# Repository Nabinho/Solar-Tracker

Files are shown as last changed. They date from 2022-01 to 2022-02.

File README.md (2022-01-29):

# Solar-Tracker
Solar Tracker project with Arduino platform.

Project based on [RoboCore's Solar Panel](https://www.robocore.net/fonte/painel-solar-2w) with TEMT600 ambient light sensors. Controlled by Teensy 3.2, Pololu A-Star Micro and Open Log Module. HMI made with LCD 16x2 with I2C interface and M5Stack CardKB.

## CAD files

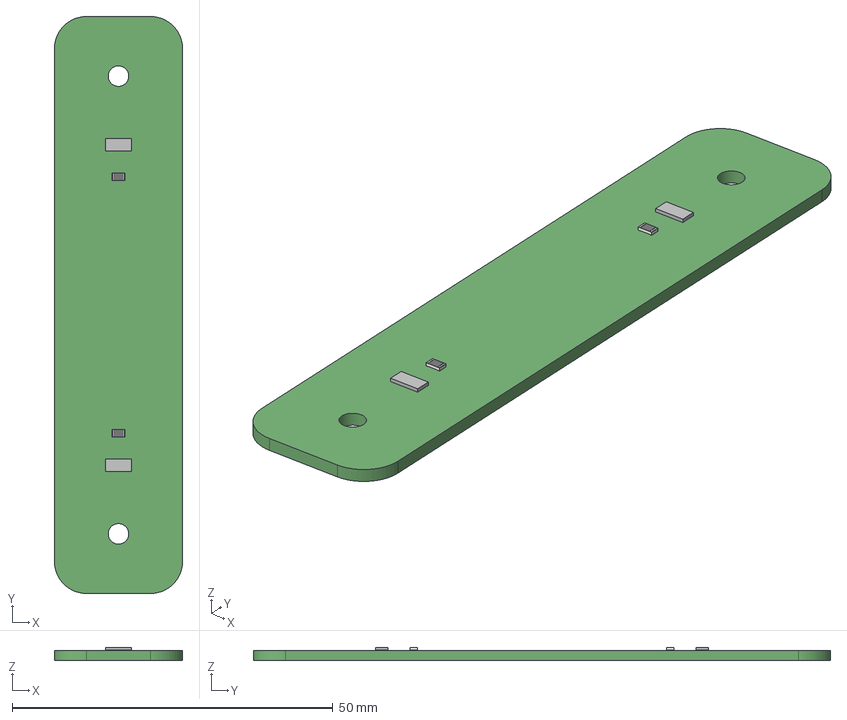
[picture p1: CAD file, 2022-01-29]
SolarTracker_Project/Electronic/TEMT6000_SolarPanel_Sensor/TEMT6000_SolarPanel_Sensor.step
20.0 x 90.0 x 2.10 mm

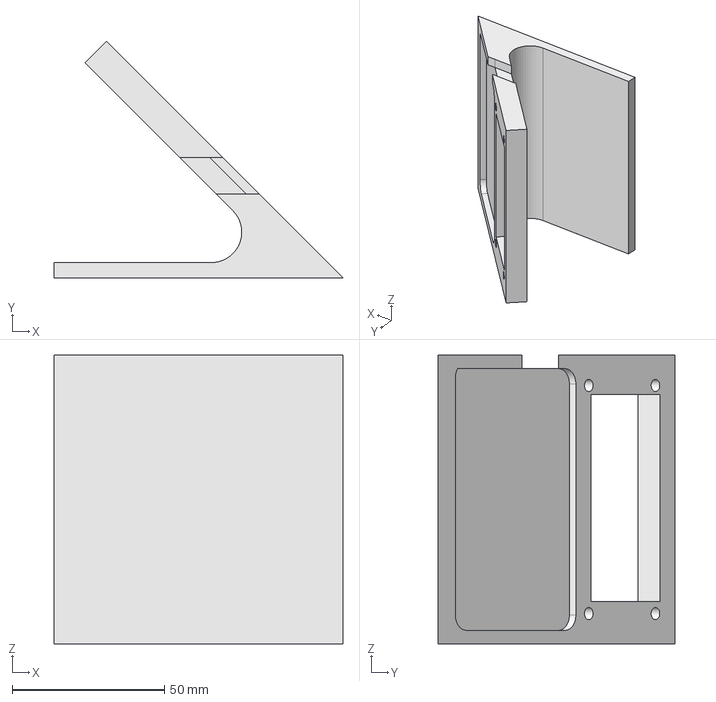
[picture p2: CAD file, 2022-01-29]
SolarTracker_Project/Mecanic/IHM_support.FCStd
95.0 x 77.8 x 95.0 mm

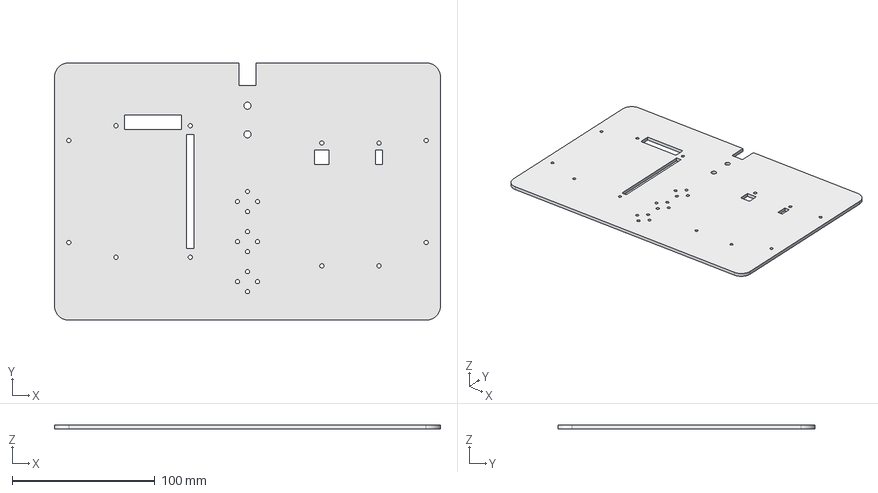
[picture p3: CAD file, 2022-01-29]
SolarTracker_Project/Mecanic/Solar_Panel_Support.FCStd
270.0 x 180.0 x 3.00 mm

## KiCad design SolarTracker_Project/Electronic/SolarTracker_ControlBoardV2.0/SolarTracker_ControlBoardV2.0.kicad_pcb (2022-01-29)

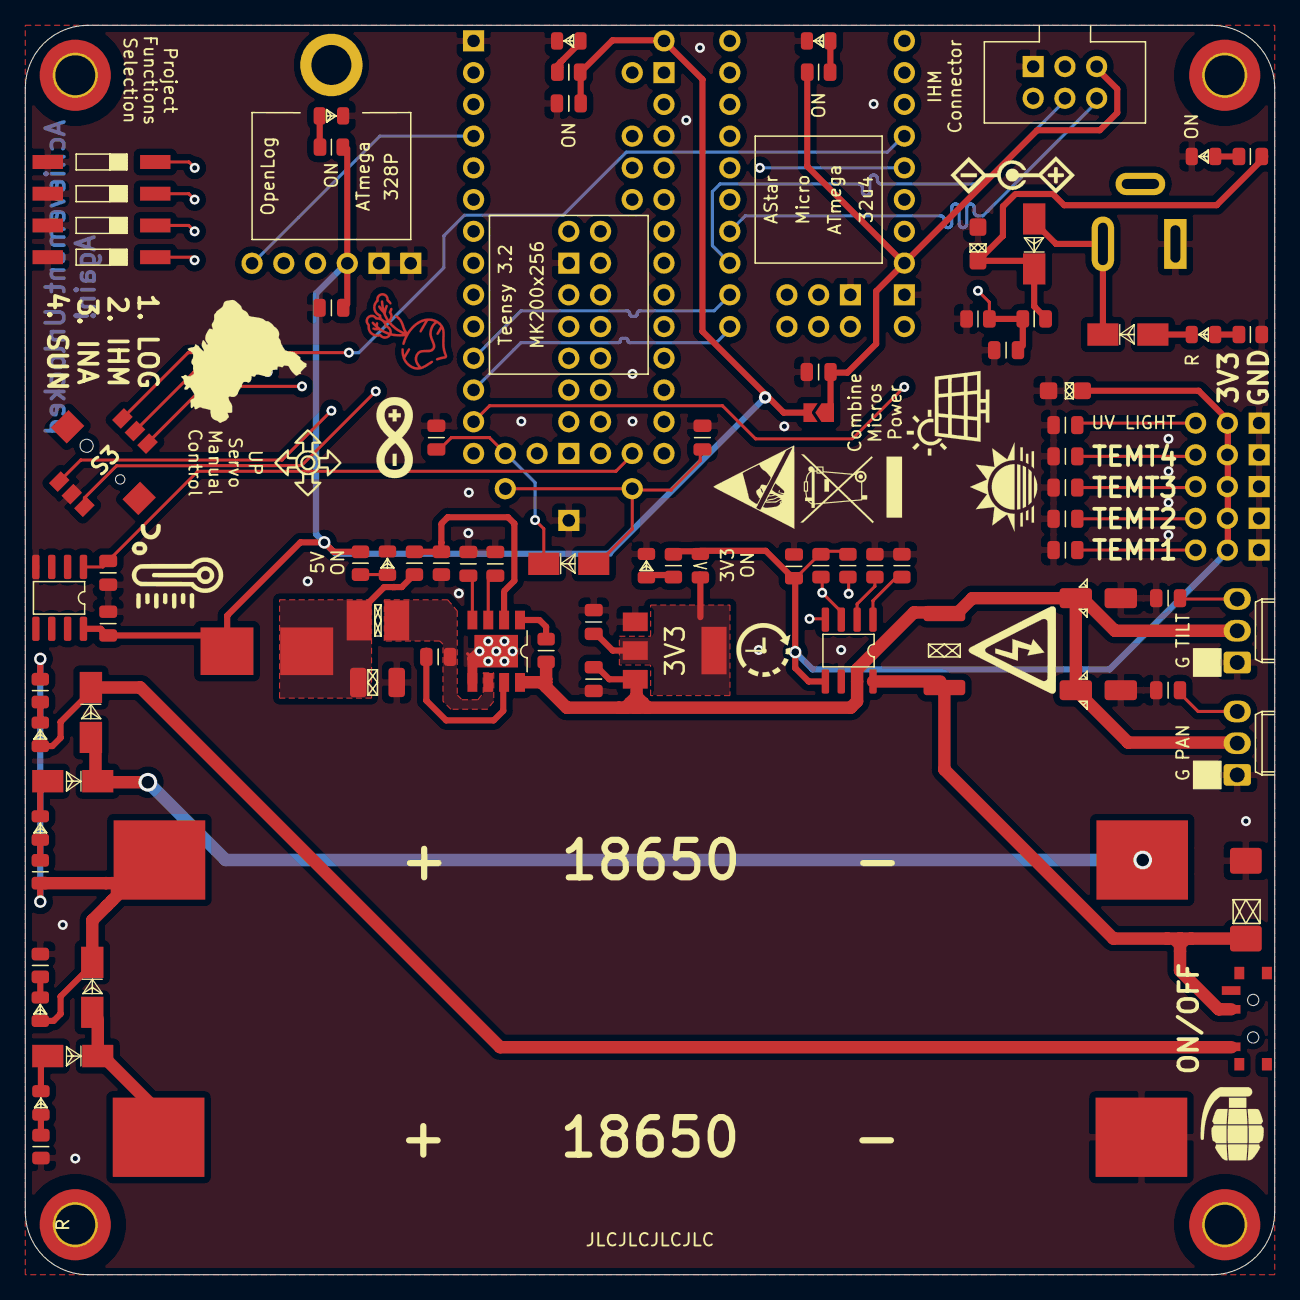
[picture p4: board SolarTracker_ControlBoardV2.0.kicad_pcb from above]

Board: 4 copper layers, 100.0 x 100.0 mm, 88 parts (0 on the bottom side), 66 nets.

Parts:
BT1, BT2: 18650; BatteryHolder_Keystone_1042_1x18650
BT3: CR2032; CR2032_BatteryHolder_Vertical
C1: 22uF; CP_EIA-7343-31_Kemet-D
C2, C5, C11, C12, C18, C20, C22, C23, C24, C25, C26, C27: 1uF; C_0805_2012Metric
C3, C4: 10uF; CP_Elec_4x5.3
C6, C7, C10, C13, C14, C15, C16, C17, C19: 100nF; C_0805_2012Metric
C8: 47uF; CP_EIA-3528-21_Kemet-B
C9, C21: 10uF; CP_EIA-3216-18_Kemet-A
D1, D4: RED; LED_0805_2012Metric
D2, D5, D12, D18: M7; D_SMA
D3, D6, D13: SS34; D_SMA
D7, D8, D9, D10, D14: B; LED_0805_2012Metric
D11: R; LED_0805_2012Metric
D15, D16, D17: G; LED_0805_2012Metric
F1: Fuse; FUSE_0154004.DR
F2: Fuse; Fuse_0805_2012Metric
J1: Servo_Pan; Molex_KK-254_AE-6410-03A_1x03_P2.54mm_Vertical
J2: Servo_Tilt; Molex_KK-254_AE-6410-03A_1x03_P2.54mm_Vertical
J3: Barrel_Jack_Switch; BarrelJack_Wuerth_6941xx301002
J4: Conn_03x05_Male; PinHeader_3x05_P2.54mm_Vertical
J5: Conn_02x03_Odd_Even; IDC-Header_2x03_P2.54mm_Vertical
JP1: SolderJumper_2_Open; SolderJumper-2_P1.3mm_Open_TrianglePad1.0x1.5mm
L1: 3,3uH; CD32
R1, R2, R3, R4, R10, R14, R15, R25, R26, R27: 1k; R_0805_2012Metric
R5: 100; R_2512_6332Metric
R6, R7, R16: 10k; R_0805_2012Metric
R8, R9: 4k7; R_0805_2012Metric
R11: 100k; R_0805_2012Metric
R12: 124k; R_0805_2012Metric
R13: 22k1; R_0805_2012Metric
R17: 15k; R_0805_2012Metric
R18: 12k; R_0805_2012Metric
S3: SKRHABE010
SW1: SW_SPDT; SW_SPDT_PCM12
SW2: SW_DIP_x04; SW_DIP_SPSTx04_Slide_9.78x12.34mm_W8.61mm_P2.54mm
U1: INA219AxD; SOIC-8_3.9x4.9mm_P1.27mm
U2: AP65552SP-13; Diodes-AP65552SP-13-06_2015-0-0
U3: Teensy3.2; Teensy_3.2
U4: LM35-D; SOIC-8_3.9x4.9mm_P1.27mm
U5: OpenLog
U6: AStar_Micro
U7: AMS1117-3.3; SOT-223-3_TabPin2

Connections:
5V: C22.1, J5.1, JP1.1, R25.1, U6.13
+3V3: C2.1, C21.1, F2.1, J4.1, R8.1, R9.1, R10.2, U1.5
+5V: C12.1, C18.1, C20.2, F1.1, JP1.2, R14.2, R26.1, R27.1, U3.33, U4.8, U5.4
A0: R7.1, U1.2
A1: R6.1, U1.1
AStar_SCL: J5.2, U6.7
AStar_SDA: J5.4, U6.8
A_SolarPanel: C10.1, R17.2, R18.1, U3.28
BS: C7.1, U2.7
BT_A: S3.1, U6.19
BT_B: S3.4, U6.18
BT_C: S3.3, U6.17
BT_D: S3.6, U6.16
BT_M: S3.2, U6.20
DIP1: SW2.1, U3.8
DIP2: SW2.2, U3.7
DIP3: SW2.3, U3.6
DIP4: SW2.4, U3.5
FB: R12.2, R13.1, U2.2
GND: BT1.2, BT3.2, C1.2, C2.2, C3.2, C4.2, C5.2, C6.2, C8.2, C9.2, C10.2, C11.2, C12.2, C13.2, C14.2, C15.2, C16.2, C17.2, C18.2, C19.2, C20.1, C21.2, C22.2, C23.2, C24.2, C25.1, C26.2, C27.2, D9.1, D10.1, D14.1, D15.1, D16.1, D17.1, J1.1, J2.1, J3.2, J4.7, J5.5, R1.2, R3.2, R6.2, R7.2, R13.2, R15.2, R18.2, S3.5, SW2.5, SW2.6, SW2.7, SW2.8, U1.6, U2.5, U2.9, U3.1, U3.17, U3.53, U4.4, U5.5, U5.6, U6.12, U6.21, U7.1
LM35: C19.1, U3.19, U4.1
unnamed: BT1.1, D2.1, D3.2
unnamed: BT2.1, D5.1, D6.2
unnamed: BT3.1, C11.1, D18.2
unnamed: C5.1, U2.3
unnamed: C6.1, U2.4
unnamed: C8.1, F1.2, L1.2, R12.1
unnamed: C24.1, F2.2, U7.2
unnamed: D1.1, D2.2
unnamed: D1.2, R1.1
unnamed: D4.1, D5.2
unnamed: D4.2, R2.1
unnamed: D7.1, R4.1
unnamed: D8.1, R3.1
unnamed: D9.2, R10.1
unnamed: D10.2, R14.1
unnamed: D11.1, D12.2
unnamed: D11.2, R15.1
unnamed: D12.1, D13.2, J3.1
unnamed: D14.2, R16.1
unnamed: D15.2, R25.2
unnamed: D16.2, R26.2
unnamed: D17.2, R27.2
unnamed: R11.2, U2.1
SW: C7.2, L1.1, U2.6
Servo_Pan: C26.1, J1.3, U6.6
Servo_Tilt: C25.2, J2.3, U6.5
TEMT1: C13.1, J4.2, U3.21
TEMT2: C14.1, J4.3, U3.22
TEMT3: C15.1, J4.4, U3.23
TEMT4: C16.1, J4.5, U3.24
Teensy_RX1: U3.2, U5.3
Teensy_RX2: U3.11, U6.9
Teensy_Reset1: U3.4, U5.1
Teensy_Reset2: U3.13, U6.15
Teensy_SCL: R9.2, U1.4, U3.26
Teensy_SDA: R8.2, U1.3, U3.25
Teensy_TX1: U3.3, U5.2
Teensy_TX2: U3.12, U6.10
UV: C17.1, J4.6, U3.27
VBAT1: BT2.2, D3.1, D8.2, R2.2, R4.2
VBAT2: D6.1, D7.2, SW1.1
VBUS: C3.1, C4.1, C23.1, J1.2, J2.2, R5.2, R11.1, U1.7, U2.8, U7.3
VDD: C1.1, R5.1, SW1.2, U1.8
VPP: C9.1, D13.1, R16.2, R17.1
VS: C27.1, D18.1, U3.15

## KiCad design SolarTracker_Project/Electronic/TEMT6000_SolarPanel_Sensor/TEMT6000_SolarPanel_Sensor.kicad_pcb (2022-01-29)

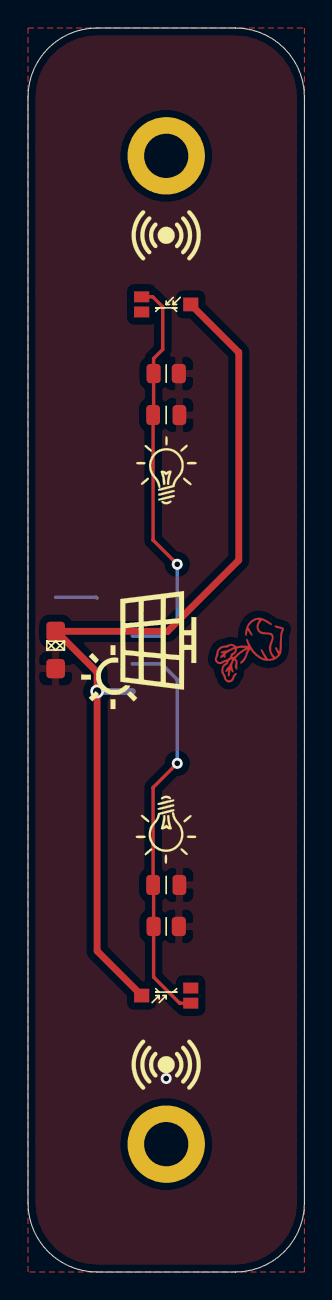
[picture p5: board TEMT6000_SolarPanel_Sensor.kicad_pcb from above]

Board: 2 copper layers, 20.0 x 90.0 mm, 8 parts (1 on the bottom side), 4 nets.

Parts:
C1: 1uF; CP_EIA-3216-18_Kemet-A
C2, C3: 100nF; C_0805_2012Metric
J1: Conn_01x04; JST_PH_S4B-PH-SM4-TB_1x04-1MP_P2.00mm_Horizontal
Q1, Q2: TEMT6000X01; Vishay_Semiconductors-TEMT6000X01-Manufacturer_Recommended
R1, R2: 10k; R_0805_2012Metric

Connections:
+3V3: C1.1, J1.1, Q1.3, Q2.3
GND: C1.2, C2.2, C3.2, J1.4, R1.2, R2.2
Signal1: C2.1, J1.2, Q1.1, R1.1
Signal2: C3.1, J1.3, Q2.1, R2.1

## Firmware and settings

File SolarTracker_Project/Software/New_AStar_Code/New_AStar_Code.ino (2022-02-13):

/*******************************************************************************
  Solar Tracker Project Slave Code
  (v1.5 - 12/02/2022)

  Created by: @Nabinho
  CardKB IHM Reference - https://docs.m5stack.com/#/en/unit/cardkb

  This program is free software: you can redistribute it and/or modify
  it under the terms of the GNU Lesser General Public License as published by
  the Free Software Foundation, either version 3 of the License, or
  (at your option) any later version (<https://www.gnu.org/licenses/>).
*******************************************************************************/

//------------------------------------------------------------------------------
//Code Setup

// Board Selection Verification
#if !defined(ARDUINO_AVR_A_STAR_32U4) // Pololu A Star Micro
#error Use this code with Pololu AStar Micro
#endif

// DEBUG Definition
// Comment for cancel serial monitor DEBUG
#define DEBUG

//Libraries
#include <LiquidCrystal_I2C.h>
#include <Servo.h>
#include <Arduino.h>
#include <EEPROM.h>

//IHM Communication Variables
//LCD variables
#define LCD_ADDR 0x3F
#define N_COLUMNS 16
#define N_ROWS 2
LiquidCrystal_I2C lcd(LCD_ADDR, N_COLUMNS, N_ROWS);
//Keyboard variables
// Keyboard variables
#define CARDKB_ADDR 0x5F
char leitura;
String letter;
String message;
String leituraHEX;
int index;
bool log_read = false;

//Times Variables
unsigned long time_before = 0;
const int SECOND = 2000;

//Servos Objects
Servo servo_pan;
Servo servo_tilt;

//Servo Control Variables
int memory_pan = 0;
int memory_tilt = 1;
int pos_pan;
int pos_tilt;

//Pan servo variables
const int pin_pan = 4;
const int pan_max = 180;
const int pan_min = 0;

//Tilt servo variables
const int pin_tilt = 5;
const int tilt_max = 180;
const int tilt_min = 90;

//Joystick middle button variables
const int pin_middle = 7;
int readingM;
int buttonMState;
int lastButtonMState = HIGH;
unsigned long lastMDebounceTime = 0;
const int MdebounceDelay = 500;
bool manual_control = false;

//Joystick left-right variables
const int pin_left = A0;
const int pin_right = 8;
int readingL;
int readingR;
int buttonLState;
int buttonRState;
int lastButtonLState = HIGH;
int lastButtonRState = HIGH;
unsigned long lastLRDebounceTime = 0;
const int LRdebounceDelay = 100;

//Joystick up-down variables
const int pin_up = 6;
const int pin_down = 9;
int readingU;
int readingD;
int buttonUState;
int buttonDState;
int lastButtonUState = HIGH;
int lastButtonDState = HIGH;
unsigned long lastUDDebounceTime = 0;
const int UDdebounceDelay = 100;

//------------------------------ IHM Handler -----------------------------------
void IHM_control() {

  if (!manual_control) {
    Wire.requestFrom(CARDKB_ADDR, 1);
    while (Wire.available()) {
      leitura = Wire.read();
      if (leitura != 0) {
        leituraHEX = String(leitura, HEX);
#ifdef DEBUG
        Serial.print("CardKB Reading = ");
        Serial.println(leitura);
        Serial.print("CardKB Reading in HEX = ");
        Serial.println(leituraHEX);
#endif
        if (leituraHEX == "8") {
          index = message.length();
          message.remove(index - 1);
          index = message.length();
          lcd.clear();
          lcd.print("Message:  " + message);
#ifdef DEBUG
          Serial.println("Backspace pressed");
          Serial.print("Message - ");
          Serial.println(message);
#endif
        } else if (leituraHEX == "ff8b") {
          message = "";
#ifdef DEBUG
          Serial.println("Delete pressed");
          Serial.print("message erased.");
          Serial.println(message);
#endif
        } else if (leituraHEX == "d" || leituraHEX == "a3") {
#ifdef DEBUG
          Serial.println("Enter pressed - Sending message and waiting return...");
#endif
          log_read = true;
          digitalWrite(LED_BUILTIN, HIGH);
        } else if (leituraHEX == "1b" || leituraHEX == "ff80") {
#ifdef DEBUG
          Serial.println("Esc pressed - leaving message request mode...");
#endif
          digitalWrite(LED_BUILTIN, LOW);
          Serial1.print("IHMREADOFF");
          lcd.clear();
          log_read = false;
          message = "";
        } else if (index > 6) {
#ifdef DEBUG
          Serial.print("Message too long - ignoring last character pressed - ");
          Serial.println(message);
#endif
          message.remove(index - 1);
          lcd.clear();
          lcd.print("Message:  " + message);
          lcd.setCursor(0, 1);
          lcd.print("Message too long");
        } else{
          letter = String(leitura);
          message += letter;
          index = message.length();
          lcd.clear();
          lcd.print("Message:  " + message);
#ifdef DEBUG
          Serial.print("Message - ");
          Serial.println(message);
#endif
        }
      }
    }
  }
  
}

//----------------------------- Servo Handler ----------------------------------
void servo_control(){

  //Reads button states
  readingM = digitalRead(pin_middle);

  //Debounces time update
  if (readingM != lastButtonMState){
    // reset the debouncing timer
    lastMDebounceTime = millis();
  }

  //Debounce verification
  if ((millis() - lastMDebounceTime) > MdebounceDelay){
    if (readingM != buttonMState){
      buttonMState = readingM;
      if (buttonMState == LOW){
        //Inverts manual control funtion state
        manual_control = !manual_control;
        if (manual_control){
          //Attaches Servos
#ifdef DEBUG
          Serial.println("ENTERING MANUAL MODE");
#endif
          lcd.clear();
          lcd.print(" ENTERED SERVOS ");
          lcd.setCursor(0, 1);
          lcd.print(" MANUAL CONTROL ");
        }
        else{
          //Detaches Servos
#ifdef DEBUG
          Serial.println("EXITING MANUAL MODE");
#endif
          lcd.clear();
          lcd.print(" EXITED SERVOS ");
          lcd.setCursor(0, 1);
          lcd.print(" MANUAL CONTROL ");
        }
      }
    }
  }

  //Updates button reading
  lastButtonMState = readingM;

  //Checks manual control function selection
  if (manual_control){

    //updates left-right buttons reading
    readingL = digitalRead(pin_left);
    readingR = digitalRead(pin_right);

    //Debounce time update
    if (readingL != lastButtonLState || readingR != lastButtonRState){
      // reset the debouncing timer
      lastLRDebounceTime = millis();
    }

    //Debounce verification
    if ((millis() - lastLRDebounceTime) > LRdebounceDelay){
      if (readingL != buttonLState || readingR != buttonRState){
        servo_pan.attach(pin_pan);
        buttonLState = readingL;
        buttonRState = readingR;
        if (buttonLState == LOW){
          pos_pan++;
          if (pos_pan >= pan_max){
            pos_pan = pan_max;
          }
        }
        if (buttonRState == LOW){
          pos_pan--;
          if (pos_pan <= pan_min){
            pos_pan = pan_min;
          }
        }
        servo_pan.write(pos_pan);
        EEPROM.write(memory_pan, pos_pan);
#ifdef DEBUG
        Serial.print("Pan Servo Position - ");
        Serial.print(pos_pan);
        Serial.print(" | Tilt Servo Position - ");
        Serial.println(pos_tilt);
#endif
        lcd.clear();
        lcd.print("PAN POS:    ");
        lcd.print(pos_pan);
        lcd.setCursor(0, 1);
        lcd.print("TILT POS:   ");
        lcd.print(pos_tilt);
      }
    }

    //Updates left-right buttons reading
    lastButtonRState = readingR;
    lastButtonLState = readingL;
    servo_pan.detach();

    //updates up-down buttons reading
    readingU = digitalRead(pin_up);
    readingD = digitalRead(pin_down);

    //Debounce time update
    if (readingU != lastButtonUState || readingD != lastButtonDState){
      // reset the debouncing timer
      lastUDDebounceTime = millis();
    }

    //Debounce verification
    if ((millis() - lastUDDebounceTime) > UDdebounceDelay){
      if (readingU != buttonUState || readingD != buttonDState){
        servo_tilt.attach(pin_tilt);
        buttonUState = readingU;
        buttonDState = readingD;
        if (buttonUState == LOW){
          pos_tilt++;
          if (pos_tilt >= tilt_max){
            pos_tilt = tilt_max;
          }
        }
        if (buttonDState == LOW){
          pos_tilt--;
          if (pos_tilt <= tilt_min){
            pos_tilt = tilt_min;
          }
        }
        servo_tilt.write(pos_tilt);
        EEPROM.write(memory_tilt, pos_tilt);
#ifdef DEBUG
        Serial.print("Pan Servo Position - ");
        Serial.print(pos_pan);
        Serial.print(" | Tilt Servo Position - ");
        Serial.println(pos_tilt);
#endif
        lcd.clear();
        lcd.print("PAN POS:    ");
        lcd.print(pos_pan);
        lcd.setCursor(0, 1);
        lcd.print("TILT POS:   ");
        lcd.print(pos_tilt);
      }
    }

    //Updates up-down buttons reading
    lastButtonUState = readingU;
    lastButtonDState = readingD;
    servo_tilt.detach();

  }
}

//------------------------------- Code Setup -----------------------------------
void setup(){

  //System startup
#ifdef DEBUG
  Serial.begin(9600);
  Serial.println("Solar Tracker Project Made by Nabinho\nDEBUG enabled");
#endif
  Serial1.begin(9600);

  //LED configuration
  pinMode(LED_BUILTIN, OUTPUT);
  digitalWrite(LED_BUILTIN, LOW);

  //EEPROM stratup
  pos_pan = EEPROM.read(memory_pan);
  pos_tilt = EEPROM.read(memory_tilt);
  delay(100);

  //Pan servo con[]
  servo_pan.attach(pin_pan);
  servo_pan.write(pos_pan);
  delay(50);
  servo_pan.detach();

  //Tilt servo configuration
  servo_tilt.attach(pin_tilt);
  servo_tilt.write(pos_tilt);
  delay(50);
  servo_tilt.detach();

  //Joystick pins configuration
  pinMode(pin_left, INPUT_PULLUP);
  pinMode(pin_right, INPUT_PULLUP);
  pinMode(pin_up, INPUT_PULLUP);
  pinMode(pin_down, INPUT_PULLUP);
  pinMode(pin_middle, INPUT_PULLUP);

  //IHM configuration
  lcd.init();
  lcd.backlight();
  lcd.print(" SYSTEM    OK! ");
  delay(1000);
  lcd.clear();
#ifdef DEBUG
  Serial.println("System Started");
#endif

}

//------------------------------ Code Loop -------------------------------------
void loop(){

  //Handles Manual Servo Control Configuration
  servo_control();

  //Handles IHM Control Function
  IHM_control();

  //Every second
  if ((millis() - time_before) > SECOND){
    digitalWrite(LED_BUILTIN, !digitalRead(LED_BUILTIN));
    if (log_read && !manual_control){
      //Sends message to Master
      //Serial.println("Mensagem '" + message + "' enviada, aguardando retorno...");
      lcd.setCursor(0, 0);
      lcd.print("Message:  " + message);
      if (message == "SPPAN"){
#ifdef DEBUG
        Serial.print("Return - ");
        Serial.println(pos_pan);
#endif
        lcd.setCursor(0, 1);
        lcd.print("Reading:");
        lcd.setCursor(10, 1);
        lcd.print(pos_pan);
      } else if (message == "SPTILT"){
#ifdef DEBUG
        Serial.print("Return - ");
        Serial.println(pos_tilt);
#endif
        lcd.setCursor(0, 1);
        lcd.print("Reading:");
        lcd.setCursor(10, 1);
        lcd.print(pos_tilt);
      } else {
        Serial1.print(message);
      }
    }
    time_before = millis();
  }

  //Reads replies from Master
  if (Serial1.available() > 0){
    String leitura = Serial1.readString();
#ifdef DEBUG
    Serial.print("Return - ");
    Serial.println(leitura);
#endif
    digitalWrite(LED_BUILTIN, !digitalRead(LED_BUILTIN));
    //Handles Servos Control Messages
    if (!log_read && !manual_control){
      servo_tilt.attach(pin_tilt);
      servo_pan.attach(pin_pan);
      if (leitura == "STILTP"){
        pos_tilt += 5;
        if (pos_tilt > tilt_max)
        {
          pos_tilt = tilt_max;
        }
        servo_tilt.write(pos_tilt);
        EEPROM.write(memory_tilt, pos_tilt);
      } else if (leitura == "STILTM"){
        pos_tilt -= 5;
        if (pos_tilt < tilt_min){
          pos_tilt = tilt_min;
        }
        servo_tilt.write(pos_tilt);
        EEPROM.write(memory_tilt, pos_tilt);
      } else if (leitura == "SPANP"){
        pos_pan += 5;
        if (pos_pan > pan_max){
          pos_pan = pan_max;
        }
        servo_pan.write(pos_pan);
        EEPROM.write(memory_pan, pos_pan);
      } else if (leitura == "SPANM"){
        pos_pan -= 5;
        if (pos_pan < pan_min){
          pos_pan = pan_min;
        }
        servo_pan.write(pos_pan);
        EEPROM.write(memory_pan, pos_pan);
      }
    }

    //Hendles IHM Messages
    if (log_read && !manual_control){
      servo_tilt.detach();
      servo_pan.detach();
      if (leitura == "ERROR"){
#ifdef DEBUG
        Serial.println("Return - invalid message");
#endif
        lcd.setCursor(0, 1);
        lcd.print("Invalid message!");
        log_read = false;
      } else if (leitura == "IHMOFF"){
#ifdef DEBUG
        Serial.println("Return - IHM disabled");
#endif
        lcd.setCursor(0, 1);
        lcd.print(" IHM  Disabled! ");
        log_read = false;
      } else if (leitura == "INAOFF"){
#ifdef DEBUG
        Serial.println("Return - INA disabled");
#endif
        lcd.setCursor(0, 1);
        lcd.print(" INA  Disabled! ");
        log_read = false;
      } else if (leitura == "LOGOFF"){
#ifdef DEBUG
        Serial.println("Return - OpenLog disabled");
#endif
        lcd.setCursor(0, 1);
        lcd.print(" LOG  Disabled! ");
        log_read = false;
      } else if (leitura == "SUNOFF"){
#ifdef DEBUG
        Serial.println("Return - Solar Pannel read disabled");
#endif
        lcd.setCursor(0, 1);
        lcd.print(" SUN  Disabled! ");
        log_read = false;
      } else{
#ifdef DEBUG
        Serial.print("Response to request = ");
        Serial.println(leitura);
#endif
        lcd.clear();
        lcd.setCursor(0, 1);
        lcd.print(leitura);
      }
    }
  }
  
}
//------------------------------------------------------------------------------

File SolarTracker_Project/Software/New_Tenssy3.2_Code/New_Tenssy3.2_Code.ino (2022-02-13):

/*******************************************************************************
  Solar Tracker Project Master Code
  (v1.5 - 12/02/2022)

  Created by: @Nabinho

  This program is free software: you can redistribute it and/or modify
  it under the terms of the GNU Lesser General Public License as published by
  the Free Software Foundation, either version 3 of the License, or
  (at your option) any later version (<https://www.gnu.org/licenses/>).
*******************************************************************************/

//------------------------------------------------------------------------------
//Code Setup

// Board Selection Verification
#if !defined(__MK20DX256__) // Teensy 3.2
#error Use this code with Teensy 3.2
#endif

// DEBUG Definition
// Comment for cancel serial monitor DEBUG
#define DEBUG

//Libraries
#include <Wire.h>
#include <EEPROM.h>
#include <TimeLib.h>
#include <Arduino.h>
#include <Adafruit_INA219.h>

//OpenLog File Variables
char buff[50];
const int log_memory = 0;
int fileNumber;

//Reset Pins
const int resetOpenLog = 2;
const int resetAStar = 11;

//Times Variables
unsigned long time_before = 0;
const int SECOND = 1000;
unsigned long before_read = 0;

//Message Received Variable
String reading;

//DIP Pins
const int LOG_DIP = 3;
const int IHM_DIP = 4;
const int MMA_DIP = 5;
const int INA_DIP = 6;
int DIP[4] = {3, 4, 5, 6};
int DIPArraySize = sizeof(DIP) / sizeof(DIP[0]);

//DIP Booleans
bool OpenLog;
bool IHM;
bool SUN_read;
bool INA_read;
bool * bool_values[4] = {&OpenLog, &IHM, &SUN_read, &INA_read};
bool ihm_read = false;
String AuxBuffer;

//Light Sensors Global Variables
//Update with new pins and new resistors values
int TEMT_sensors[4] = {A1, A0, A2, A3};
float TEMT_resistors[4] = {9940.00, 10000.00, 9920.00, 10000.00};
float lux_TEMT[4];
int TEMTArraysSize = sizeof(TEMT_sensors) / sizeof(TEMT_sensors[0]);
float BOTTOMAVERAGE;
float RIGHTAVERAGE;
float LEFTAVERAGE;
float TOPAVERAGE;
const float ACCEPTABLE_DIFFERENCE = 50.0;

//UV Light Sensor Variables
const int UV_sensor = A14;
int UV_index;

//LM35 Variables
const int LM35 = A17;
float temperature;

//Solar panel voltage reading variables
const int Solar_pin = A7;
//Update with real values
const float R1 = 15000.00;
const float R2 = 12000.00;
float solar_panel_voltage;
float efficiency;

//INA219 Object
Adafruit_INA219 ina219;

//INA219 Variables
float shuntvoltage;
float busvoltage ;
float loadvoltage;
float current_mA;
float power_mW;

//Diode constant dropout voltage
//Update with real values if necessary
const float diode_voltage = 0.50;

//------------------------------- DIP Selector Handler -------------------------
void check_dip_selections () {

  for (int i = 0; i < DIPArraySize; i++) {
    if (digitalRead(DIP[i]) == LOW) {
      delay(50);
      if (digitalRead(DIP[i]) == LOW) {
        *bool_values[i] = true;
      }
    } else {
      delay(50);
      if (digitalRead(DIP[i]) == HIGH) {
        *bool_values[i] = false;
      }
    }
  }
  String StrBuffer;
  StrBuffer += "OpenLog = ";
  StrBuffer += String(OpenLog);
  StrBuffer += "\nIHM = ";
  StrBuffer += String(IHM);
  StrBuffer += "\nSolar Pannel = ";
  StrBuffer += String(SUN_read);
  StrBuffer += "\nINA = ";
  StrBuffer += String(INA_read);
#ifdef DEBUG
  Serial.println(StrBuffer);
#endif
  if (OpenLog) {
    Serial1.println(StrBuffer);
  }

}

//------------------------------- Sensors Handler ------------------------------
void read_sensors() {

  //Reads LM35
  analogRead(LM35);
  analogRead(LM35);
  temperature = (3.3 * analogRead(LM35) * 100.00) / 1024.00;
  String StrBuffer;
  StrBuffer += "Temperature = ";
  StrBuffer += String(temperature);
  StrBuffer += " C";
#ifdef DEBUG
  Serial.println(StrBuffer);
#endif
  if (OpenLog) {
    Serial1.println(StrBuffer);
  }
  StrBuffer = "";

  //Reads TEMT sensors and converts to LUX
  for (int i = 0; i < TEMTArraysSize; i++) {
    analogRead(TEMT_sensors[i]);
    analogRead(TEMT_sensors[i]);
    float volts = analogRead(TEMT_sensors[i]) * 3.3 / 1024.00;
    float amps = volts / TEMT_resistors[i];
    float microamps = amps * 1000000.00;
    lux_TEMT[i] = microamps * 2.00;
    String StrBuffer;
    StrBuffer += "TEMT6000";
    StrBuffer += String(i+1);
    StrBuffer += " = ";
    StrBuffer += String(lux_TEMT[i]);
    StrBuffer += " LUX";
#ifdef DEBUG
    Serial.println(StrBuffer);
#endif
    if (OpenLog) {
      Serial1.println(StrBuffer);
    }
  }

  //Reads UV Sensor
  analogRead(UV_sensor);
  analogRead(UV_sensor);
  int UV_reading = analogRead(UV_sensor);
  if (UV_reading <= 10) {
    UV_index = 0;
  } else if (UV_reading > 10 && UV_reading <= 46) {
    UV_index = 1;
  } else if (UV_reading > 46 && UV_reading <= 65) {
    UV_index = 2;
  } else if (UV_reading > 65 && UV_reading <= 83) {
    UV_index = 3;
  } else if (UV_reading > 83 && UV_reading <= 103) {
    UV_index = 4;
  } else if (UV_reading > 103 && UV_reading <= 124) {
    UV_index = 5;
  } else if (UV_reading > 124 && UV_reading <= 142) {
    UV_index = 6;
  } else if (UV_reading > 142 && UV_reading <= 162) {
    UV_index = 7;
  } else if (UV_reading > 162 && UV_reading <= 180) {
    UV_index = 8;
  } else if (UV_reading > 180 && UV_reading <= 200) {
    UV_index = 9;
  } else if (UV_reading > 200 && UV_reading <= 221) {
    UV_index = 10;
  } else {
    UV_index = 11;
  }
  StrBuffer += "UV Index = ";
  StrBuffer += String(UV_index);
#ifdef DEBUG
  Serial.println(StrBuffer);
#endif
  if (OpenLog) {
    Serial1.println(StrBuffer);
  }

  //Reads Solar Pannel Input
  if (SUN_read) {
    analogRead(Solar_pin);
    analogRead(Solar_pin);
    solar_panel_voltage =  (analogRead(Solar_pin) * (3.3 / 1024.00) * ((R1 + R2) / R2)) + diode_voltage;
    efficiency = (7.4 / solar_panel_voltage) * 100.00;
    String StrBuffer;
    StrBuffer += "Solar Panel Voltage = ";
    StrBuffer += String(solar_panel_voltage);
    StrBuffer += " V\nEfficiency = ";
    StrBuffer += String(efficiency);
    StrBuffer += " %";
#ifdef DEBUG
    Serial.println(StrBuffer);
#endif
    if (OpenLog) {
      Serial1.println(StrBuffer);
    }
  }

  //Reads INA Sensor
  if (INA_read) {
    shuntvoltage = ina219.getShuntVoltage_mV();
    busvoltage = (ina219.getBusVoltage_V()) + (diode_voltage * 2.00);
    loadvoltage = busvoltage + (shuntvoltage / 1000.00);
    current_mA = ina219.getCurrent_mA();
    power_mW = ina219.getPower_mW();
    String StrBuffer;
    StrBuffer += "Bus Voltage = ";
    StrBuffer += String(busvoltage);
    StrBuffer += " V\nLoad Voltage = ";
    StrBuffer += String(loadvoltage);
    StrBuffer += " V\nShunt Voltage = ";
    StrBuffer += String(shuntvoltage);
    StrBuffer += " mV\nCurrent Consuption = ";
    StrBuffer += String(current_mA);
    StrBuffer += " mA\nPower Consuption = ";
    StrBuffer += String(power_mW);
    StrBuffer += "mW";
#ifdef DEBUG
    Serial.println(StrBuffer);
#endif
    if (OpenLog) {
      Serial1.println(StrBuffer);
    }
  }

}
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
